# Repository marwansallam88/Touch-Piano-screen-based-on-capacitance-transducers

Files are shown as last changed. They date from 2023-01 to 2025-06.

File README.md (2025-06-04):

# Touch Piano Screen Based On Capacitance Transducers

## Project Overview
<p align="center">
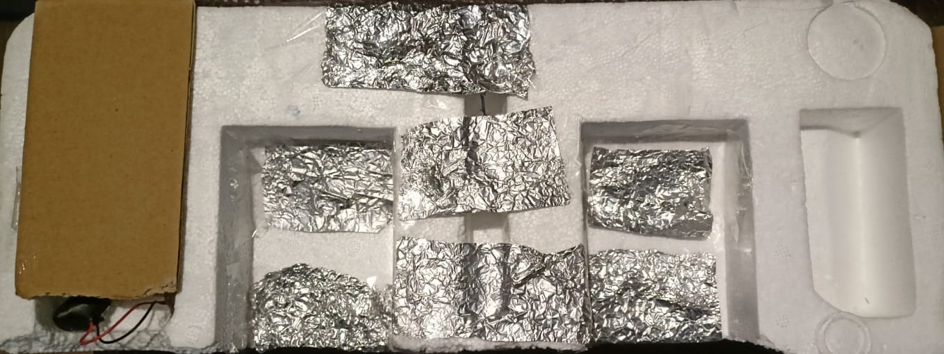
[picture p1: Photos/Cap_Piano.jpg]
Description
  
</p>

### Technical Concept
A microcontroller-based electronic piano that utilizes capacitive sensing technology to replace traditional mechanical keys. The system employs RC time constant measurements to detect touch inputs with variable sensitivity, enabling:
- Contactless note triggering
- Pressure-sensitive volume control (future implementation)
- Compact form factor with minimal moving parts

### System Architecture
-
  ```mermaid
  graph TD
      A[Capacitive Touch Pads] --> B[RC Circuit]
      B --> C[Arduino Nano]
      C --> D[PWM Tone Generation]
      D --> E[Passive Buzzer]
      C --> F[LED Feedback]

## Key Specifications

| Parameter           | Specification         | Measurement Method     |
|---------------------|------------------------|-------------------------|
| Input Range         | 1–174 ms               | RC time constant        |
| Output Resolution   | 7,908 units            | 10-bit ADC              |
| Sensitivity         | 394.4 units/ms         | Linear regression       |
| Frequency Response  | 5.7–997.6 rad/s        | Bode analysis           |
| Power Consumption   | <100mA @ 5V            | Current probe           |

---

## Technical Implementation

### Sensing System
<p align="center">
  <img src="Photos/Cap_Piano_Circuit.png" alt="Description" width="400"/>
</p>

- 7× copper PCB pads (20mm² each)  
- 1MΩ current-limiting resistors  
- CapacitiveSensor library for Arduino

### Control Unit
<p align="center">
  <img src="Photos/Cap_Piano_PCB.png" alt="Description" width="400"/>
</p>

- ATmega328P microcontroller  
- Custom PCB layout  
- 16MHz clock frequency

### Audio Output
- Passive piezoelectric buzzer  
- PWM-generated tones (C4–B4 frequency range)  
- 8Ω impedance

### Power Management
- 18650 Li-ion cell (3.7V nominal)  
- TP4056 charging module  
- MT3608 boost converter (to 5V)

---

## Performance Characteristics

### Transfer Function
-
    ```math
          H(s) = \frac{1}{\tau s + 1}, \quad \tau \in [0.001, 0.174] \text{ s}

### Bandwidth Variation

- **Untouched:** 997.6 rad/s (159 Hz)  
- **Fully pressed:** 5.7 rad/s (0.9 Hz)

---

## Statistical Analysis

| Metric                | Value             |
|------------------------|------------------|
| Resolution             | 7,908 units       |
| Sensitivity            | 394.4 units/ms    |
| Std. Deviation         | 3.12×10⁶          |
| Signal-to-Noise Ratio  | 42 dB             |

---

## Development Progress

### Research Phase
- Capacitive sensing literature review  
- Component selection analysis

### Prototyping
- Breadboard validation  
- Initial code development

### Production
- PCB design (Eagle)  
- SMT assembly process

### Validation
- Unit testing (per key)  
- Frequency response verification  
- Power consumption measurements

---

## Future Work

### Potential Implementations
- Pressure-sensitive volume control
- Multi-touch detection
- Octave expansion (14+ keys)
- Battery optimization for >24h runtime

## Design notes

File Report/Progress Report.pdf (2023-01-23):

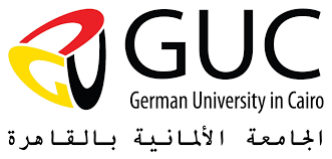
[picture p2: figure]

Faculty of Engineering and Material Science

Mechatronics Department

Assoc.Prof.Dr.Eng. Amir R. Ali

Winter 2022

# Sensor Technology ELCT 903

## Project Name: Touch Piano screen based on

## capacitance transducers

## Project Number: 35

## Team Number: 1

## Milestone Number: 5

First Member Name: | Amro Hassan (46-3027)
Second Member Name: | Ahmad Mady (46-0798)
Third Member Name: | Mohamad Magdy (46-3493)
Fourth Member Name: | Mostafa Kashaf (46-5456)
Fifth Member Name: | Marwan Sallam (46-3401)

## Brief review about touch capacitive piano:

The piano is played on a keyboard, which consists of a row of keys, and the player strikes the

keys with their fingers and thumbs to make the hammers strike the strings. As a result of the

hammers' rebound, the strings can keep vibrating at their resonance frequencies. The sounding

board receives these vibrations via the bridge, allowing for a more efficient coupling of the

acoustic energy to the air. Otherwise, the sound won't be louder than what the strings themselves

directly generate. The damper stops the string's vibration when the key is released. Then

afterwards came the digital or the electronic piano which used metal strings that magnetically

transmitted vibrations to an amplifier and loudspeaker. The analogue signal is amplified,

electronically altered with effects, and sent to speakers in an electrical piano. The upcoming

types of pianos are supposedly capacitive key pianos that can work just by touching it and most

recent projects tackle this problem. Recently, capacitive sensing has become a more attractive

and popular sensing mechanism for mechanical stimuli, especially in the sense of touch, with

good power consumption, sensitivity, and adaptive configurations of sensing. The enhancement

of the flexibility of the electrode material is an important issue since it is the primary component

of the wearable sensor. Conductive nanomaterial and polymers have been used as electrode

materials in capacitive sensors. Moreover, modified sensing interfaces and structures are also

explored to further enhance the sensitivity of the sensor. With all these advancements in the

capacitor the capacitive pianos have the possibility to work just by hovering over the keys and

can also distinguish between a long or short press thus outputting different audios or sounds on a

single key.

## Project idea and specifications:

The whole idea of the touch piano simply is using seven capacitive sensors as keys or inputs

where the microcontroller can recognize and differentiate them thus outputting seven different

audios using a passive buzzer according to the key that is pressed. Another possible feature that

can be implemented in this project is to adjust the volume of the different audio according to the

duration of the key press which are either a long press meaning higher volume and a short press

meaning lower volume and this can be done in future work once the first prototype is perfect. In

simple terms to make a capacitor all that’s needed are two parallel conductive plates which will

be the user’s finger and the part of the pcb where it has been etched separated by a dielectric

material which is air. Detecting the change of capacitance is not as easy as sensing the toggle of

the GPIO pin’s value or off. When the conductive plate is touched, the change in capacitance can

be detected using the “CapacitiveSensor” library in Arduino.

## Components list:

1x Arduino Nano | https://ram-e-shop.com/product/arduino-board-arduino-nano/
8x Resistors (1Mega Ohm) | https://ram-e-shop.com/product/fixed-resistances-125/

1x 18650 Battery cell https://ram-e-shop.com/product/lithium-rechargeable-battery-18650-3-7v-

purple-without-pins/

1x 18650 Battery cell holder https://ram-e-shop.com/product/battery-holder-18650x1/

1x 18650 battery Charging Module https://store.fut-electronics.com/collections/battery-

charger-accessory/products/lithium-battery-charger-and-protection-module

1x DC to DC Voltage Booster | https://ram-e-shop.com/product/dc-dc-200/
1x Passive Buzzer | https://store.fut-electronics.com/collections/buzzer/products/passive-

buzzer

1x PCB

# Progress Report:

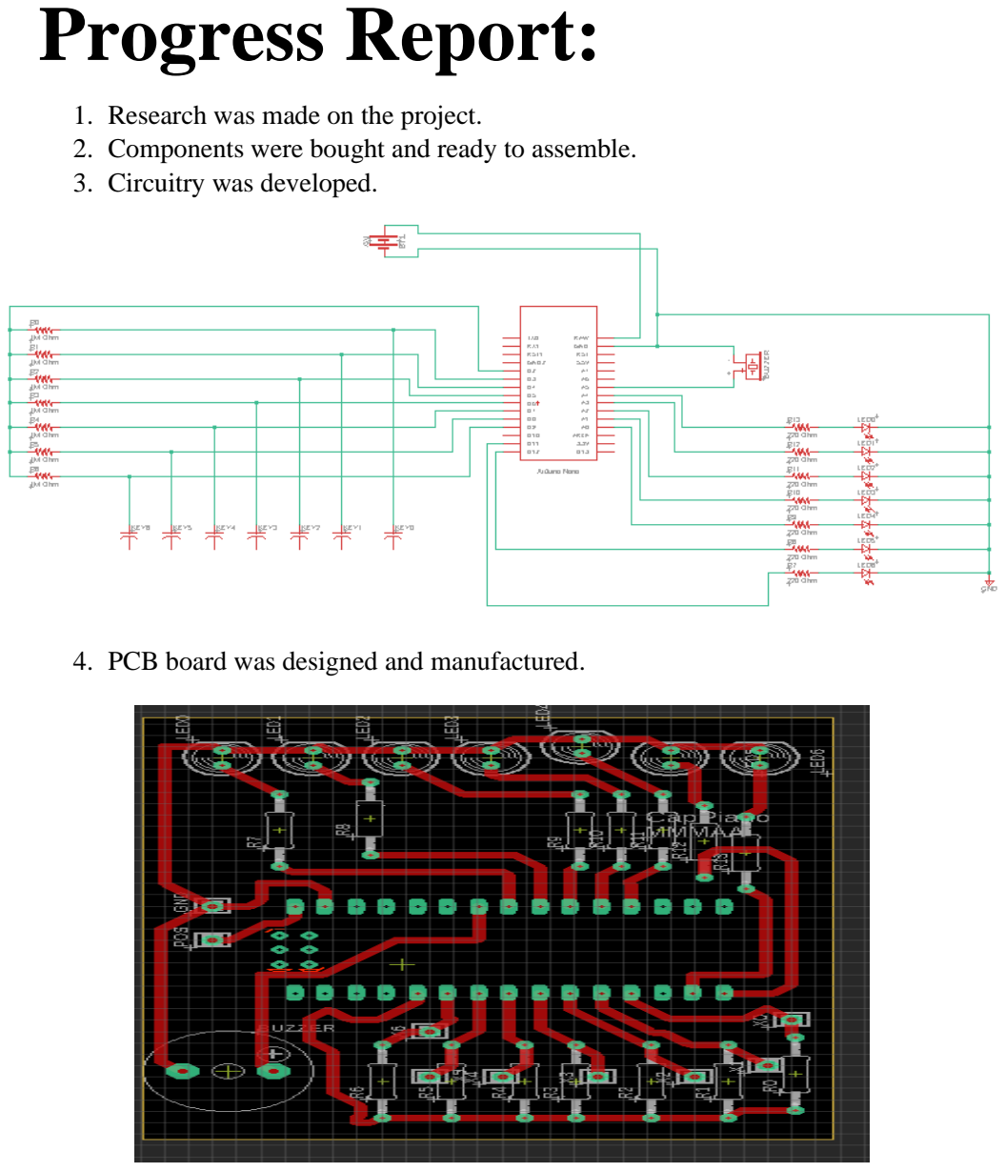
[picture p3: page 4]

1. Research was made on the project.
2. Components were bought and ready to assemble.
3. Circuitry was developed.
4. PCB board was designed and manufactured.

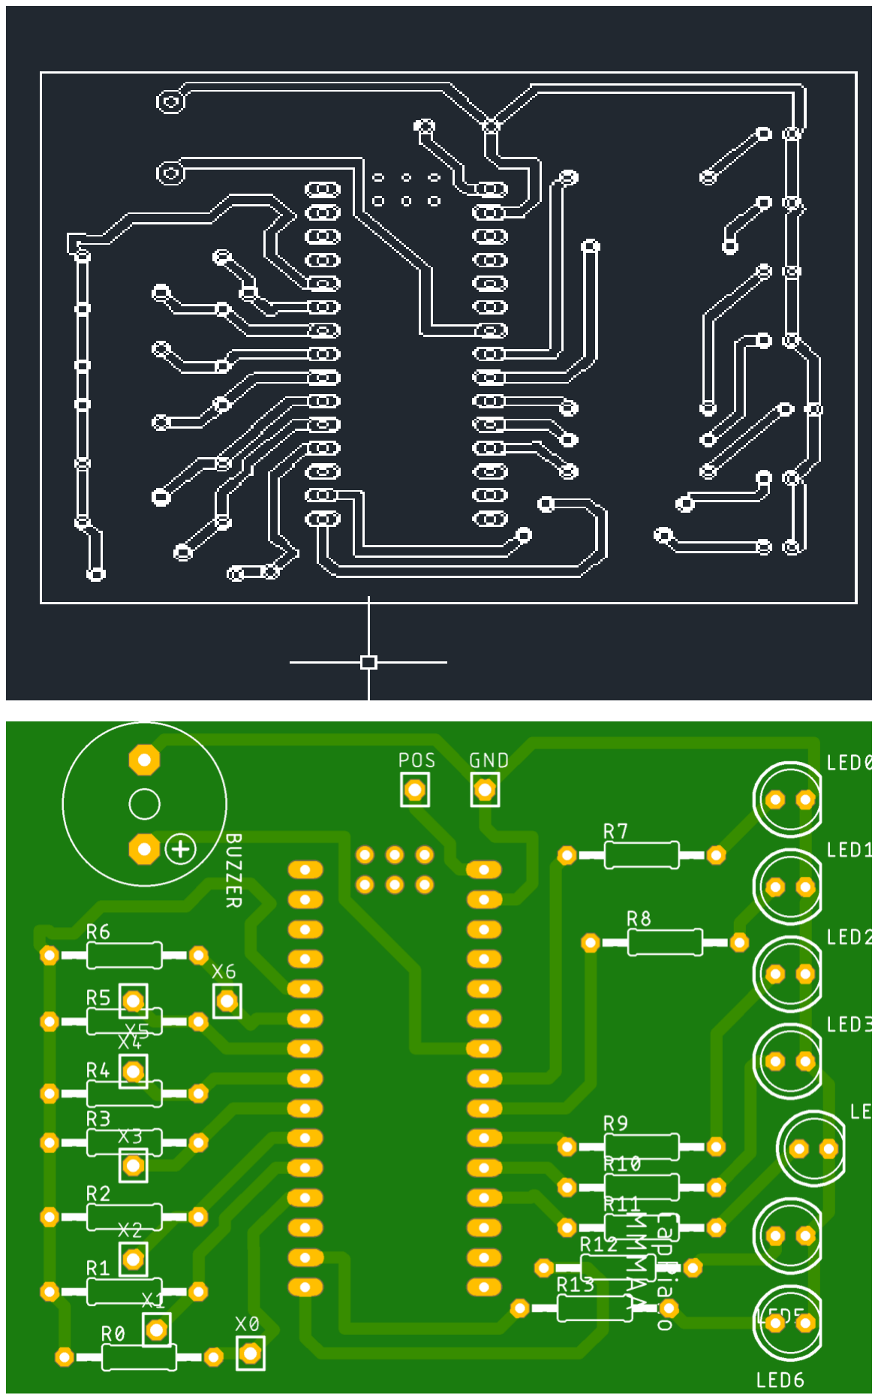
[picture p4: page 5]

5. Code was written and uploaded on Arduino. Basically, it works as follows: A sender pin sends signal to a receiver pin. Then Arduino measures the time it takes for the receiver a pin to receive the signal. As its well known in an RC circuit there some delay between input voltage and output voltage which is called the time constant and thus the Arduino measures this time and use it

to calculate the capacitance but in arbitrary units. The higher capacitance, the higher the time.

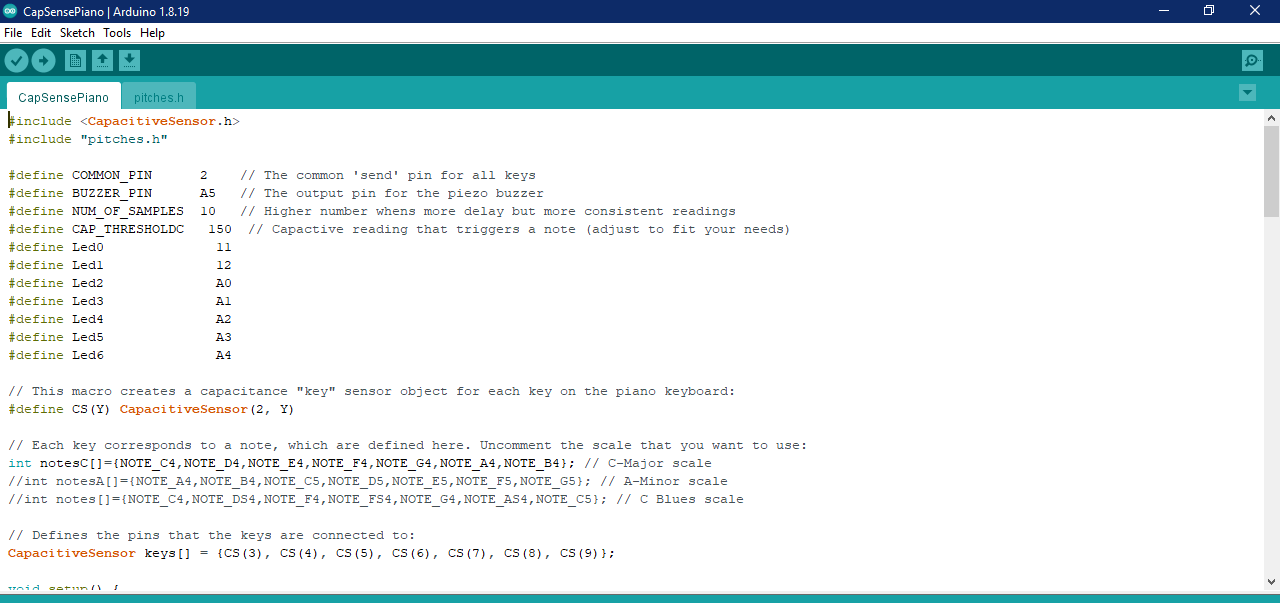
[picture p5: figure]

### 6. Code and circuitry were tested on a breadboard with the components to

make sure everything was working correctly.

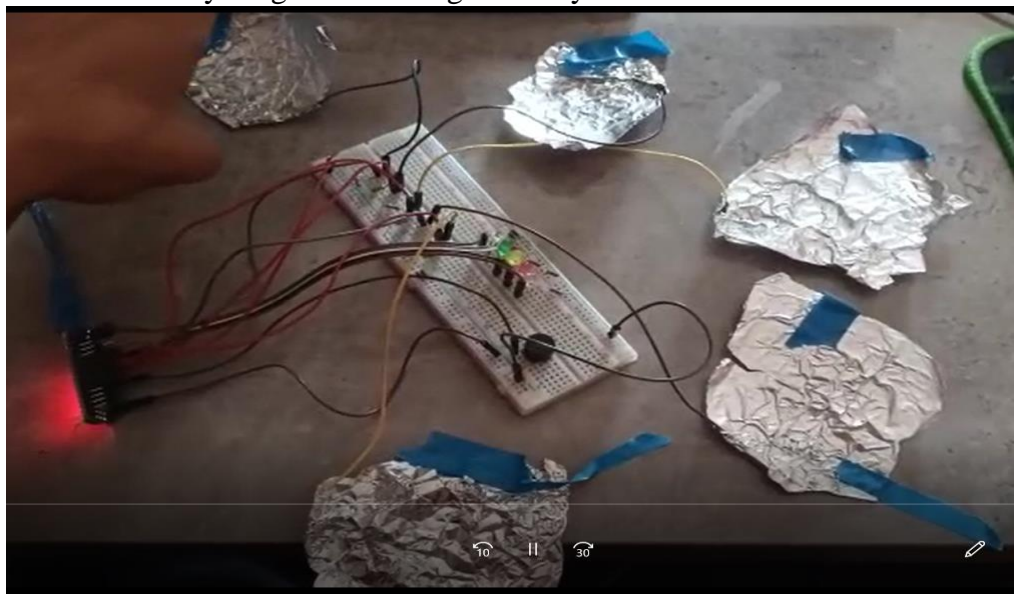
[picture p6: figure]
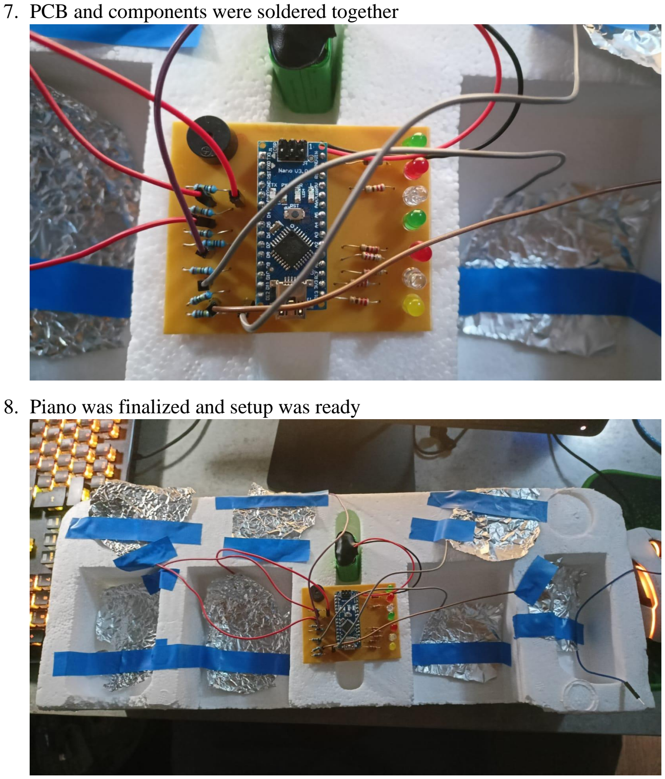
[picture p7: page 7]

### 7. PCB and components were soldered together

### 8. Piano was finalized and setup was ready

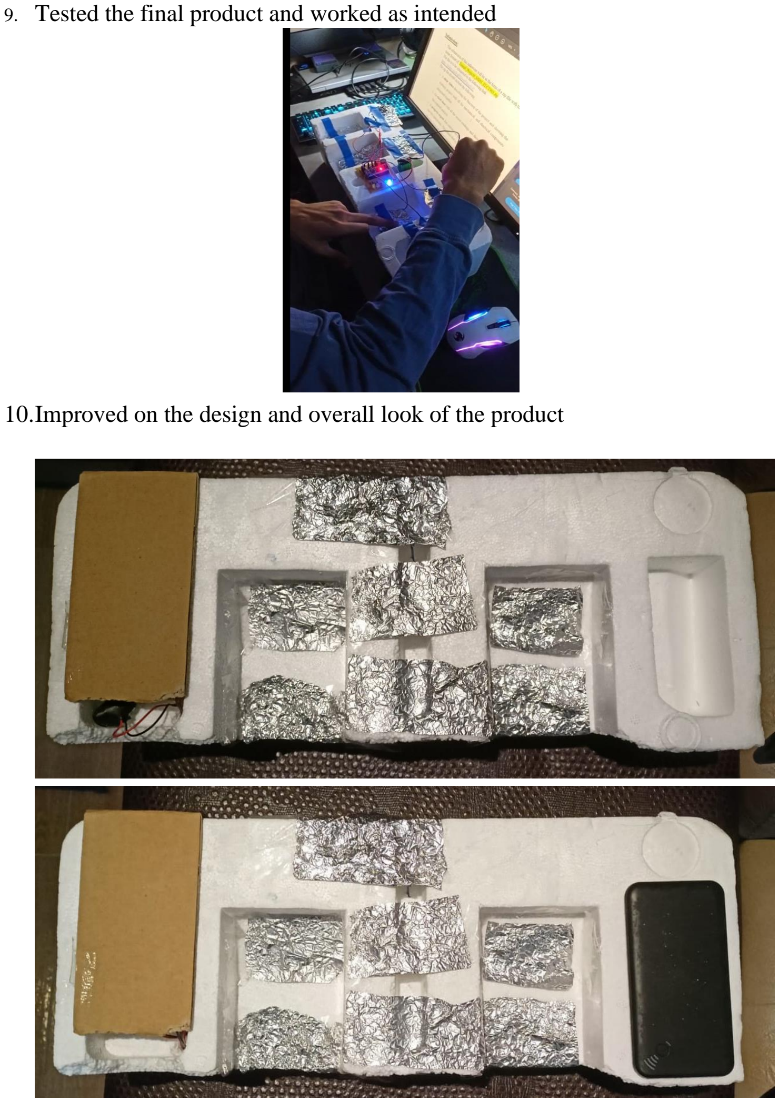
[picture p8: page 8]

### 9. Tested the final product and worked as intended

### 10.Improved on the design and overall look of the product

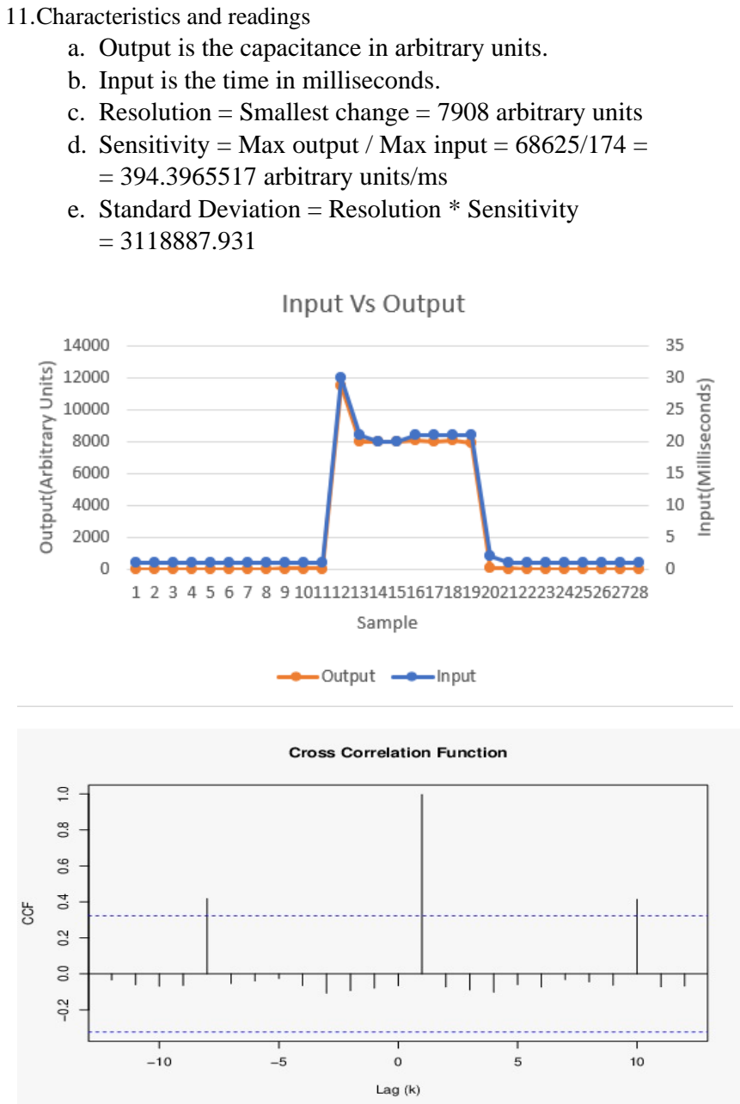
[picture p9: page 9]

### 11.Characteristics and readings

a. Output is the capacitance in arbitrary units.
b. Input is the time in milliseconds.

### c. Resolution = Smallest change = 7908 arbitrary units d. Sensitivity = Max output / Max input = 68625/174 = = 394.3965517 arbitrary units/ms e. Standard Deviation = Resolution * Sensitivity

= 3118887.931

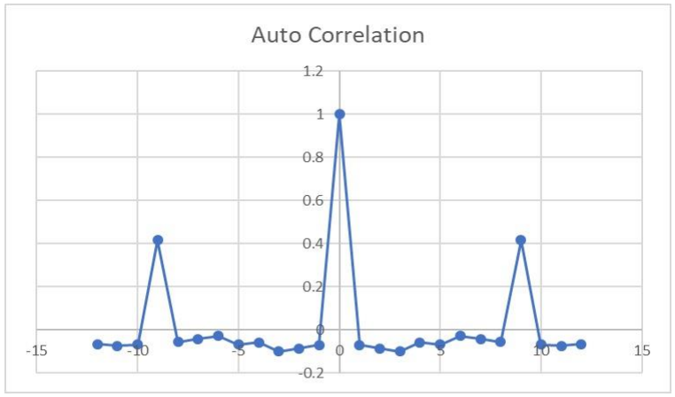
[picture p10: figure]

## Auto Correlation data

Lag | Value | Lag | Value
-12 | -0.0662062927941972 | 0 | 1
-11 | -0.0734925586884804 | 1 | -0.0705975011622147
-10 | -0.0691648171929965 | 2 | -0.0872463857498584
-9 | 0.416227475311117 | 3 | -0.100410006753664
-8 | -0.057048614727936 | 4 | -0.0579493781770414
-7 | -0.0429768616635528 | 5 | -0.0683886029991145
-6 | -0.0293223584648403 | 6 | -0.0293223584648403
-5 | -0.0683886029991145 | 7 | -0.0429768616635528
-4 | -0.0579493781770414 | 8 | -0.057048614727936
-3 | -0.100410006753664 | 9 | 0.416227475311117
-2 | -0.0872463857498584 | 10 | -0.0691648171929965
-1 | -0.0705975011622147 | 11 | -0.0734925586884804
| | 12 | -0.0662062927941972

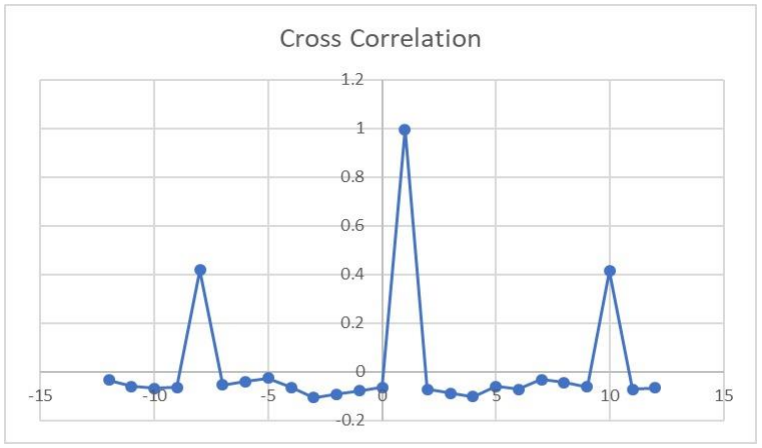
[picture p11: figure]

## Cross Correlation Data

Lag | Value | Lag | Value
-12 | -0.033552933583369 | 0 | -0.0653521394067079
-11 | -0.0606521017242916 | 1 | 0.996256864778712
-10 | -0.0679692200080865 | 2 | -0.0721238368185577
-9 | -0.0640923998830103 | 3 | -0.0888736820119851
-8 | 0.418626273898603 | 4 | -0.101987397425721
-7 | -0.0534586243471571 | 5 | -0.0596517514187829
-6 | -0.0396104332496399 | 6 | -0.0731209767303093
-5 | -0.0256047110006229 | 7 | -0.0318775446980341
-4 | -0.0648444493153413 | 8 | -0.0440842421777302
-3 | -0.106841982293459 | 9 | -0.0626140527663694
-2 | -0.0930269441936679 | 10 | 0.414056031301388
-1 | -0.0792197732757929 | 11 | -0.0715237719670072\
| | 12 | -0.0674413093998998

### f. Transfer function: The system is assumed to be a first order system with a varying

time constant as capacitance changes with respect to distance. TF = 1
Ts + 1

### Two cases were studied when pressed and when unpressed (High time and low time constant respectively)

### Test case 1: Not pressed; Low time constant around 1 millisecond

### TF = 1 0.001s + 1

### Bandwidth of the sensor when not touched at time constant 0.001: 997.6283 rad/s

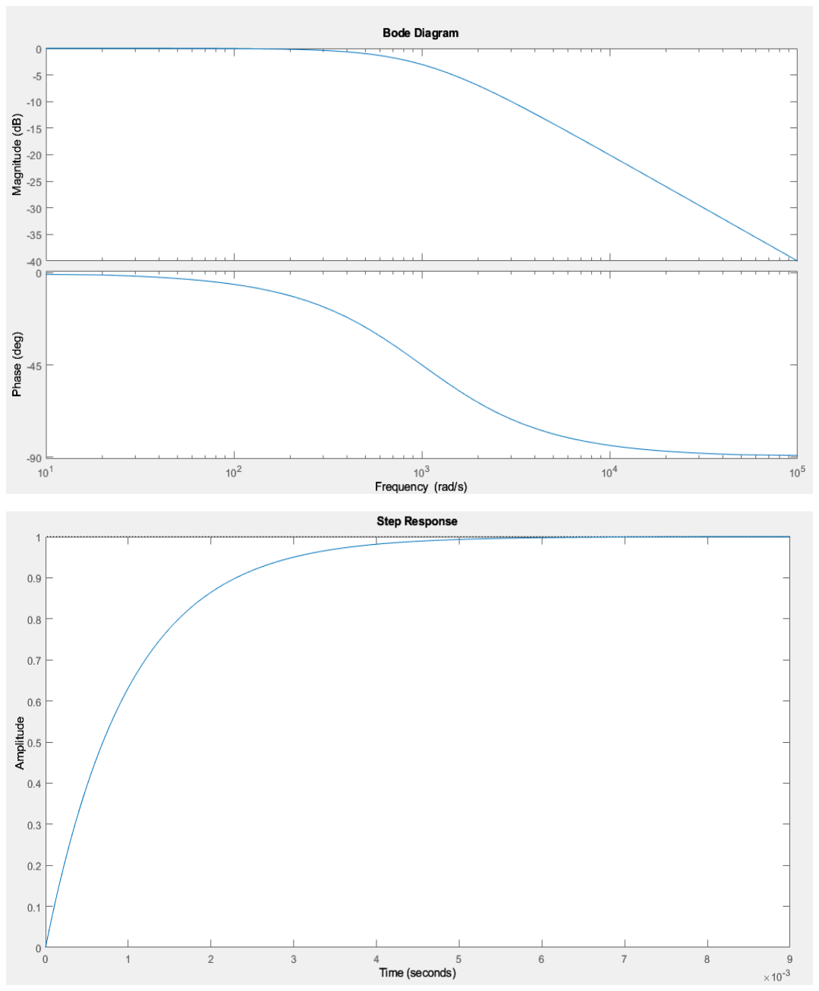
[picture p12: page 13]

### Test case 2: Pressed; How time constant around 174 milliseconds

### TF = 1 0.174s + 1

### Bandwidth of the sensor when not touched at time constant 0.174: 5.7335 rad/s

### Thus, the bandwidth can vary from 997.6283 rad/s to 5.7335

rad/s.

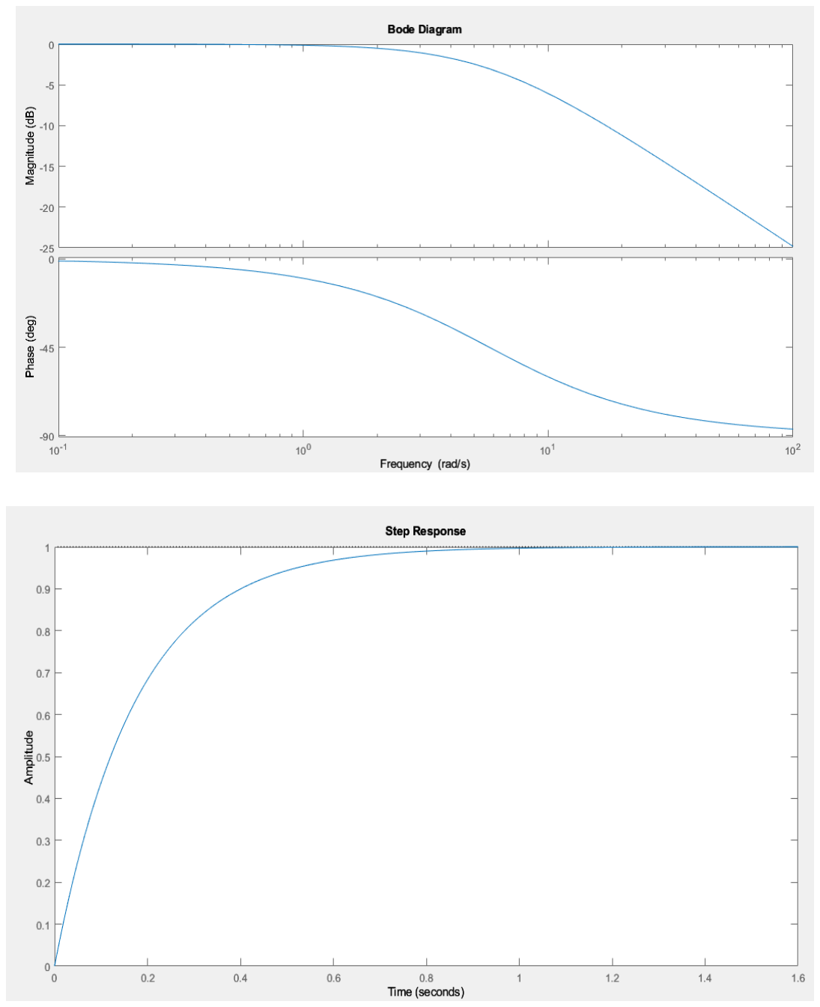
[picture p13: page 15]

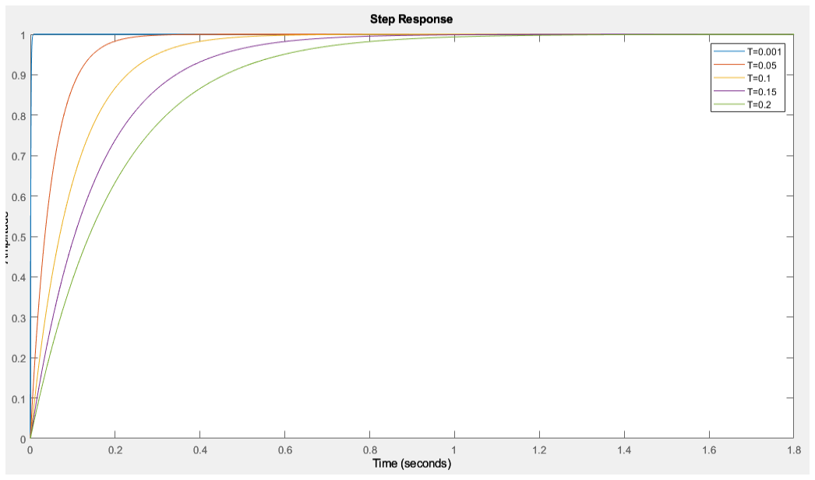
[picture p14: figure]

### As can be seen from the previous graph that as it takes longer to reach a steady

state that means the time constant is longer and thus the capacitance is higher.

### As the time constant increase, the response takes longer thus that means

capacitance has increased.

### Similarly, as seen here there is a direct relation between input which is time and

output which is capacitance in arbitrary units.

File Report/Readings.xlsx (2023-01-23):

First Readings | Second Readings | Third Readings |  | Fourth Readings |  | Info
0 | 23 | Input | Output | Input | Output
2 | 32 | 1 | 5 | 0 | 13
2 | 29 | 1 | 3 | 1 | 36 | Input is the time in milliseconds.
2 | 33 | 1 | 5 | 113 | 44652 | Output is the capacitance in arbitrary units.
3 | 32 | 1 | 3 | 1 | 31 | Resolution = Smallest change = | 7908 | arbitrary units
1 | 26 | 1 | 5 | 0 | 16 | Sensitivity = Max output / Max input = | 394.3965517 | arbitrary units/ms
3 | 31 | 1 | 10 | 0 | 13 | Standard Deviattion = Resoltuion * Sensitvity = | 3118887.931
1 | 33 | 1 | 11 | 0 | 13 | Untouched button example | Low value ranging around 0~100
3 | 33 | 1 | 10 | 0 | 16 | Touched button example | High values above 5000
1 | 30 | 1 | 12 | 0 | 13
3 | 3457 | 1 | 14 | 0 | 13
3 | 7820 | 1 | 12 | 0 | 13
3 | 11651 | 30 | 11450 | 0 | 13
0 | 11664 | 21 | 7968 | 174 | 68625
3 | 7926 | 20 | 7952 | 0 | 13
1 | 11627 | 20 | 7999 | 0 | 16
3 | 7923 | 21 | 8079
0 | 7926 | 21 | 7999
3 | 7915 | 21 | 8088
1 | 7952 | 21 | 7908
3 | 7964 | 2 | 23
0 | 7972 | 1 | 12
3 | 7922 | 1 | 11
2 | 7933 | 1 | 1
3 | 7901 | 1 | 2
3 | 7924 | 1 | 2
3 | 7860 | 1 | 1
1 | 7913 | 1 | 3
3 | 3834 | 1 | 3
0 | 31
3 | 19
3 | 13
3 | 31
1 | 30
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

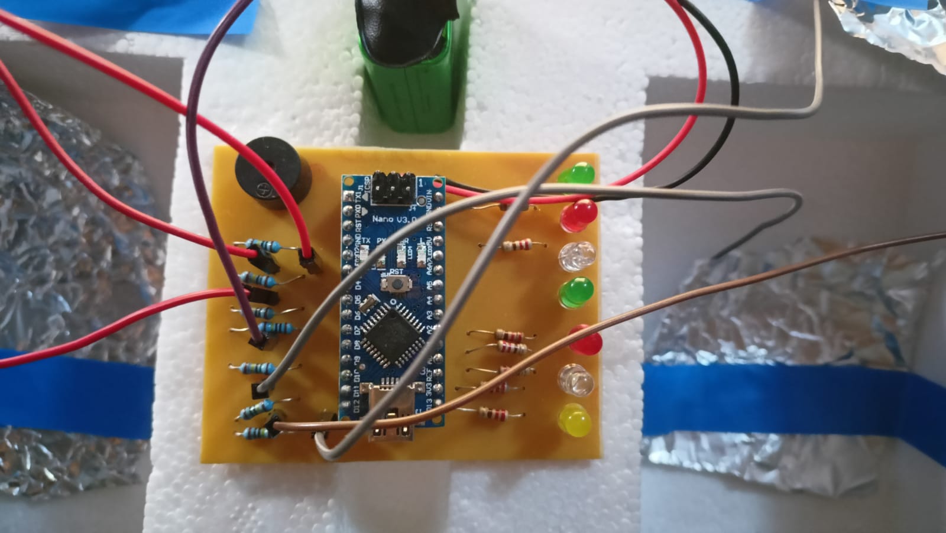
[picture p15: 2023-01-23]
Report/PCB.jpg

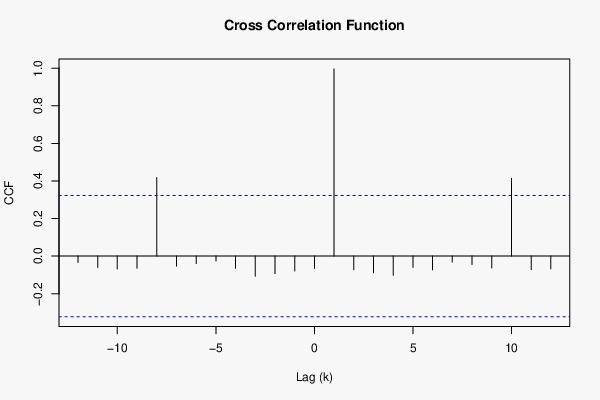
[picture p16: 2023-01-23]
Report/Cross Function.jpg

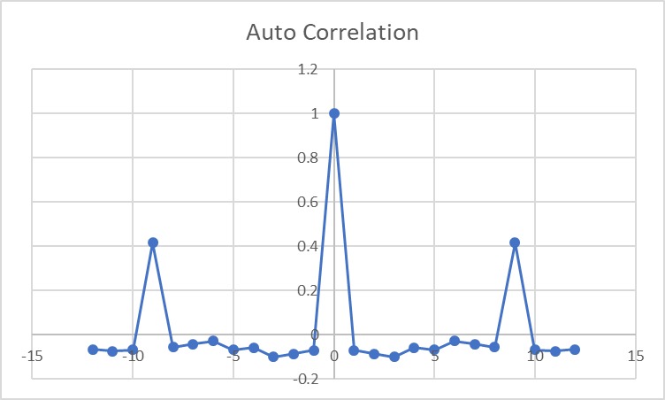
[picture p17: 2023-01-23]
Report/Auto Correlation.jpg

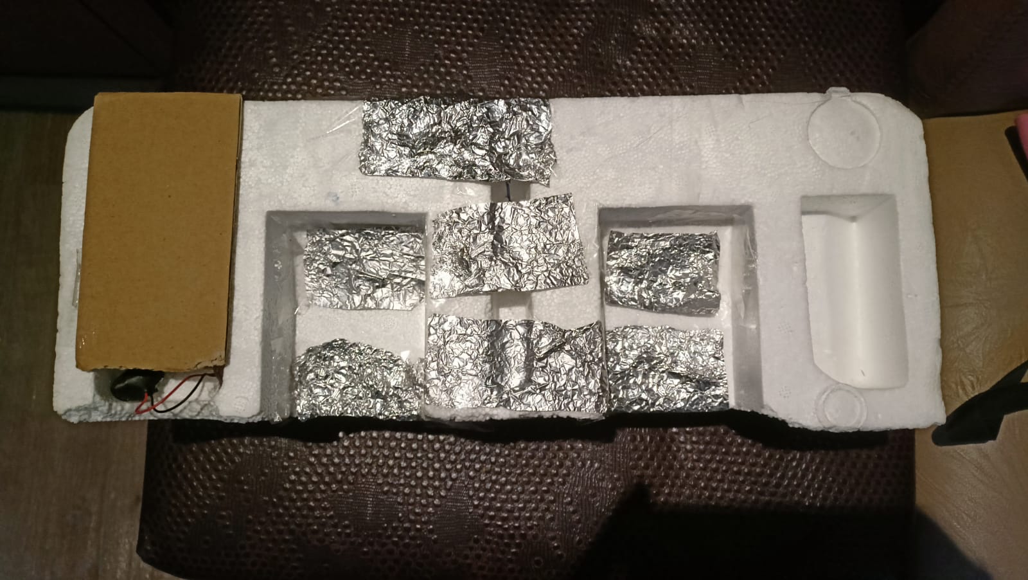
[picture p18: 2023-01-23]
Report/Finalized product.jpg

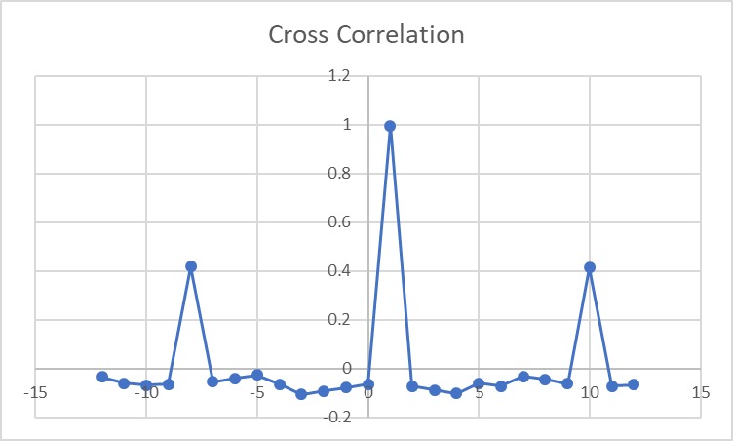
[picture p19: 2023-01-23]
Report/Cross Correlation.jpg

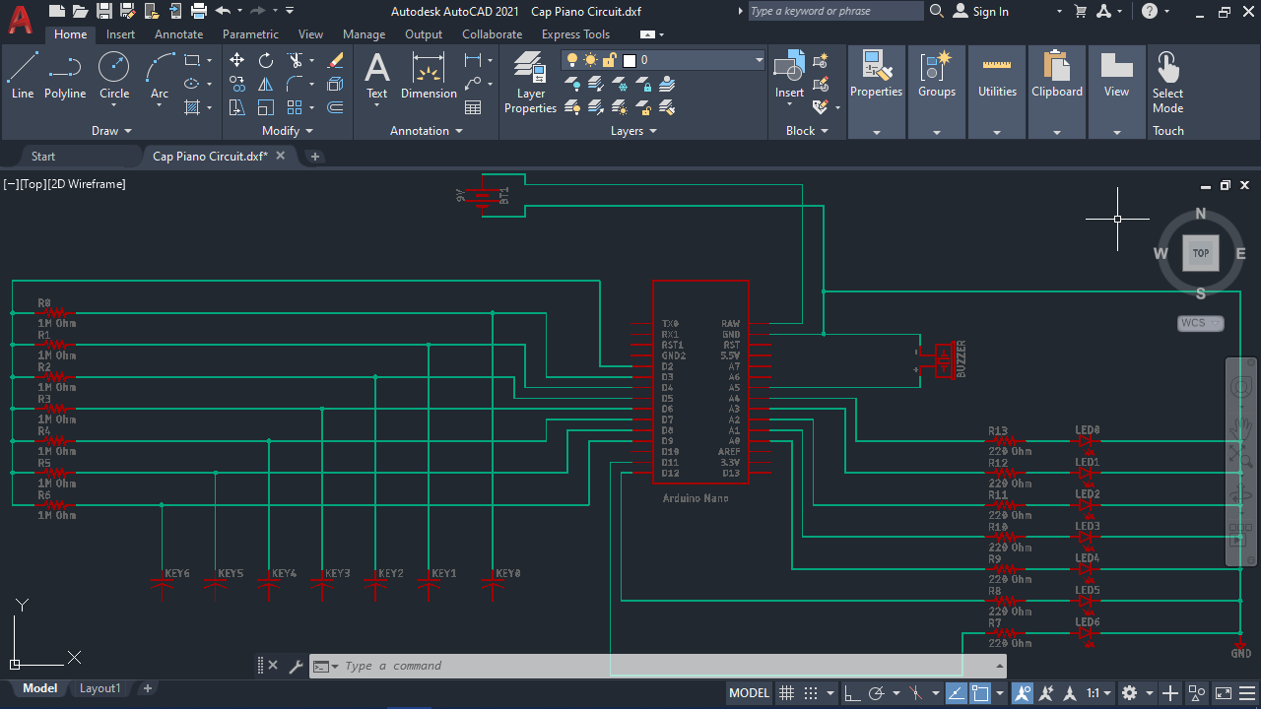
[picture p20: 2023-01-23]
Photos/Cap_Piano_Circuit.png

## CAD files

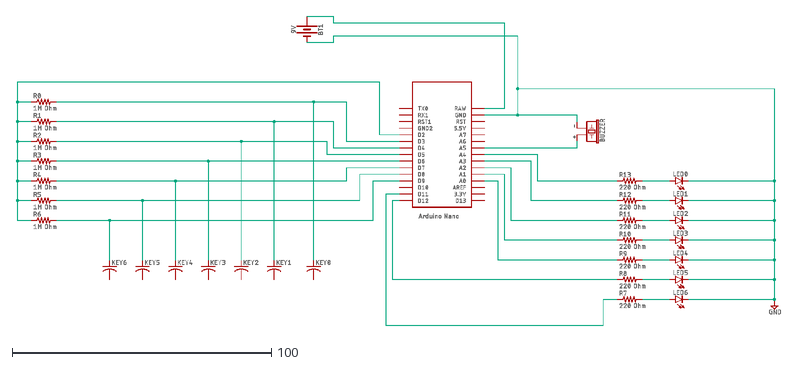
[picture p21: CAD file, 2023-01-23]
Eagle/Circuit/Cap Piano Circuit.dxf
295.1 x 119.5

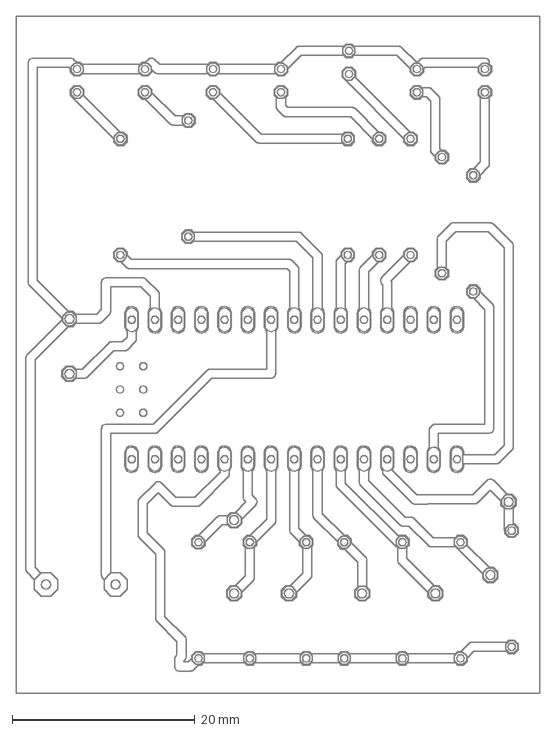
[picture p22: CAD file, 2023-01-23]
Eagle/PCB/Cap Piano - PCB.dxf
57.2 x 74.0 mm

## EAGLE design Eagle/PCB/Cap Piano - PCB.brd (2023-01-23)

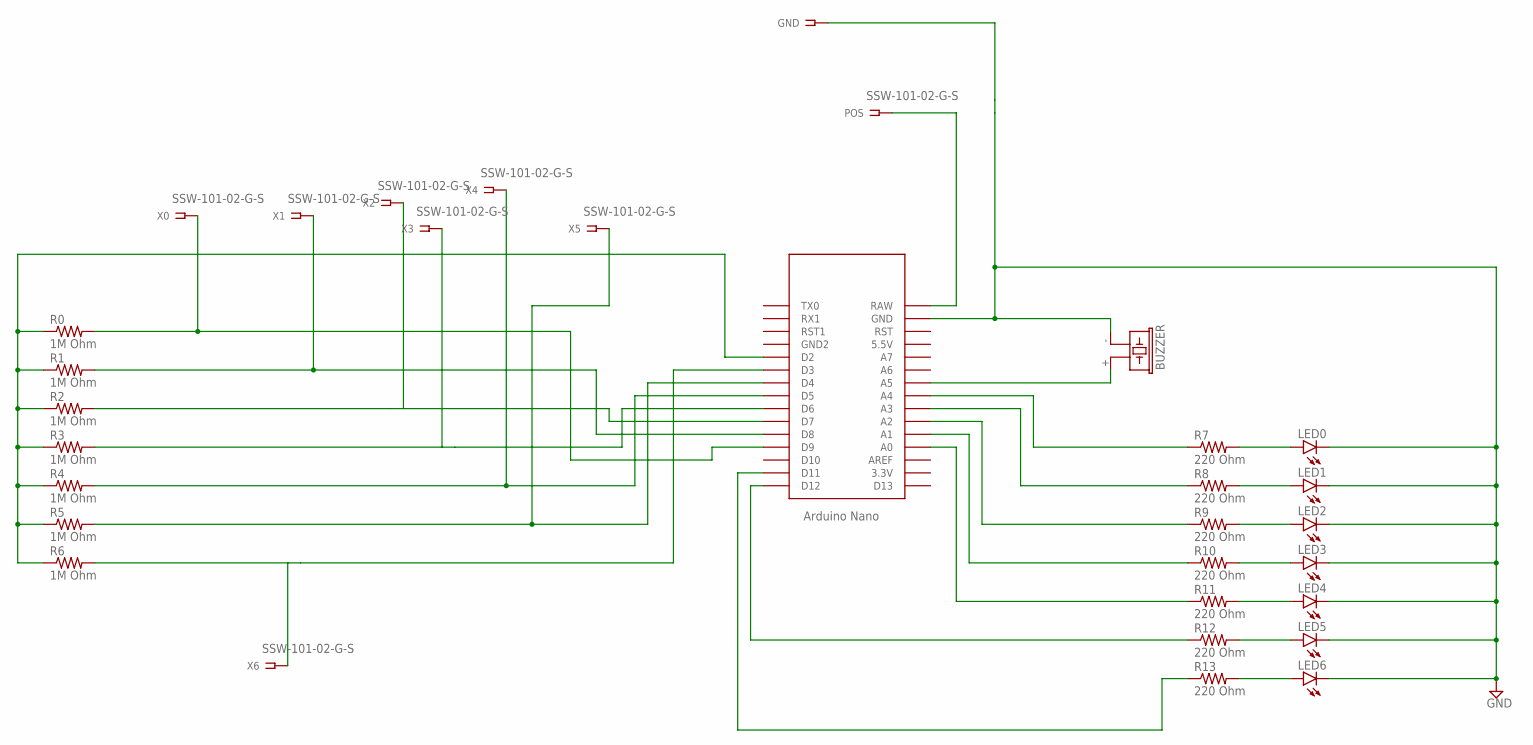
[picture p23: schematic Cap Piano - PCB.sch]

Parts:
BUZZER: F/CM12P
GND: SSW-101-02-G-S
LED0, LED1, LED2, LED3, LED4, LED5, LED6: LED5MM
POS: SSW-101-02-G-S
R0, R1, R2, R3, R4, R5, R6: 1M Ohm; 0207/12
R7, R8, R9, R10, R11, R12, R13: 220 Ohm; 0207/12
U$1: NANO
X0, X1, X2, X3, X4, X5, X6: SSW-101-02-G-S

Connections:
GND: BUZZER.- (2), GND.1, LED0.K (C), LED1.K (C), LED2.K (C), LED3.K (C), LED4.K (C), LED5.K (C), LED6.K (C), U$1.GND
unnamed: POS.1, U$1.RAW
unnamed: R5.2, U$1.D4, X5.1
unnamed: BUZZER.+ (1), U$1.A5
unnamed: R4.2, U$1.D5, X4.1
unnamed: R0.1, R1.1, R2.1, R3.1, R4.1, R5.1, R6.1, U$1.D2
unnamed: R6.2, U$1.D3, X6.1
unnamed: R3.2, U$1.D6, X3.1
unnamed: R2.2, U$1.D7, X2.1
unnamed: R1.2, U$1.D8, X1.1
unnamed: R0.2, U$1.D9, X0.1
unnamed: R13.1, U$1.D11
unnamed: R12.1, U$1.D12
unnamed: R11.1, U$1.A0
unnamed: R10.1, U$1.A1
unnamed: R9.1, U$1.A2
unnamed: R8.1, U$1.A3
unnamed: R7.1, U$1.A4
unnamed: LED0.A, R7.2
unnamed: LED1.A, R8.2
unnamed: LED2.A, R9.2
unnamed: LED3.A, R10.2
unnamed: LED4.A, R11.2
unnamed: LED5.A, R12.2
unnamed: LED6.A, R13.2

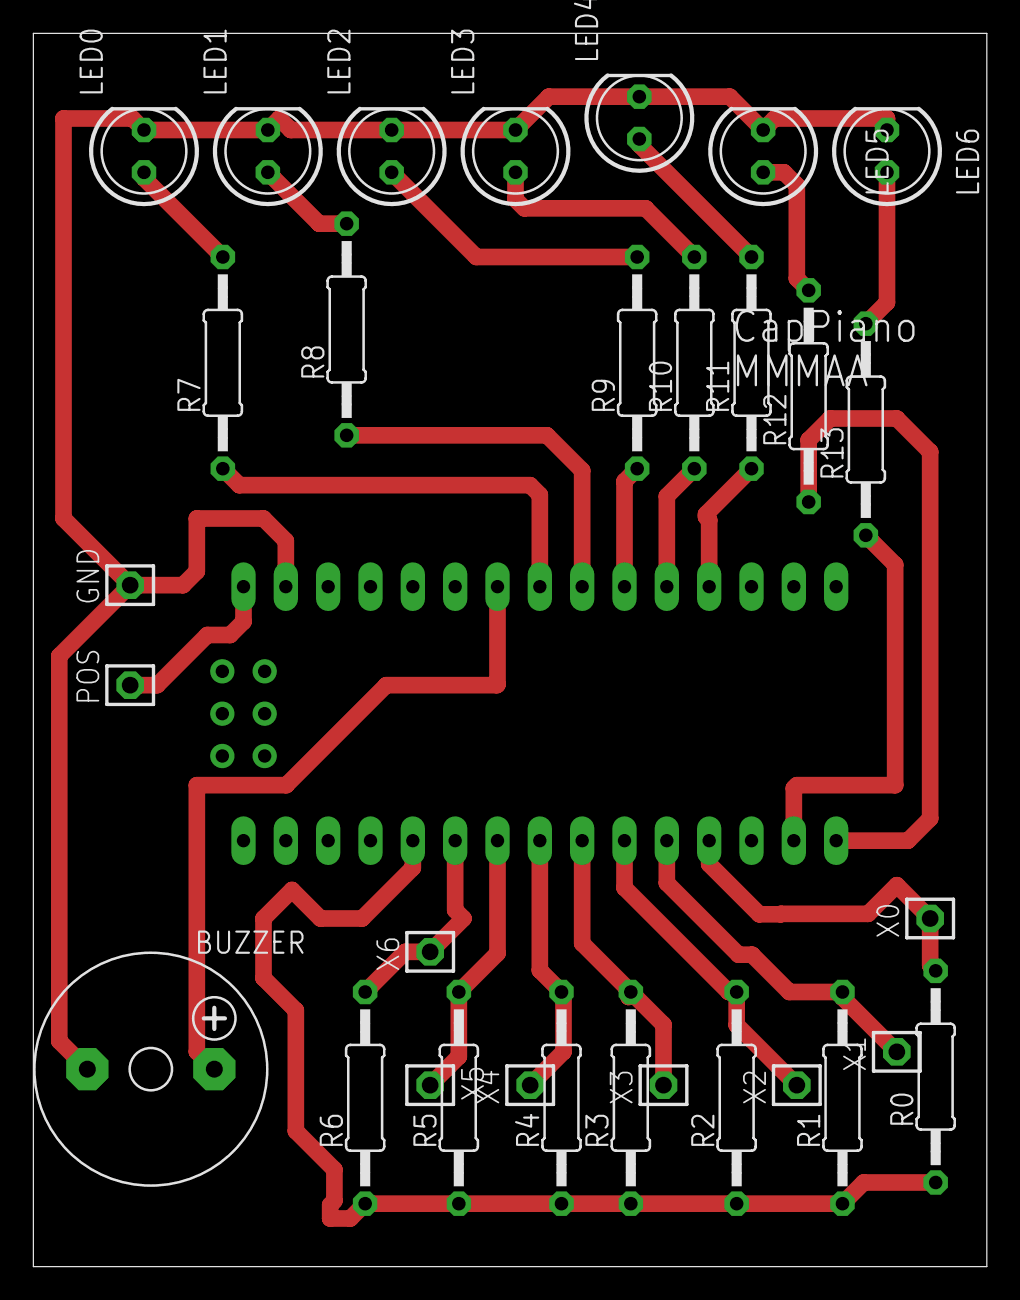
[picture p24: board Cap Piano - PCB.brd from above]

Board: 2 copper layers, 57.2 x 74.0 mm, 32 parts (0 on the bottom side), 25 nets.

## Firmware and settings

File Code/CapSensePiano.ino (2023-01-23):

#include <CapacitiveSensor.h>
#include "pitches.h"

#define COMMON_PIN      2    // The common 'send' pin for all keys
#define BUZZER_PIN      A5   // The output pin for the piezo buzzer
#define NUM_OF_SAMPLES  10   // Higher number means more delay but more consistent readings
#define CAP_THRESHOLDC   100  // Capactive reading that triggers a note (adjust to fit your needs)
#define Led0              11
#define Led1              12
#define Led2              A0
#define Led3              A1
#define Led4              A2
#define Led5              A3
#define Led6              A4

// This macro creates a capacitance "key" sensor object for each key on the piano keyboard:
#define CS(Y) CapacitiveSensor(2, Y)

// Each key corresponds to a note, which are defined here. Uncomment the scale that you want to use:
int notesC[]={NOTE_C4,NOTE_D4,NOTE_E4,NOTE_F4,NOTE_G4,NOTE_A4,NOTE_B4}; // C-Major scale
//int notesA[]={NOTE_A4,NOTE_B4,NOTE_C5,NOTE_D5,NOTE_E5,NOTE_F5,NOTE_G5}; // A-Minor scale
//int notes[]={NOTE_C4,NOTE_DS4,NOTE_F4,NOTE_FS4,NOTE_G4,NOTE_AS4,NOTE_C5}; // C Blues scale

// Defines the pins that the keys are connected to:
CapacitiveSensor keys[] = {CS(3), CS(4), CS(5), CS(6), CS(7), CS(8), CS(9)};

void setup() { 
  // Turn off autocalibrate on all channels:
  for(int i=0; i<7; ++i) {
    keys[i].set_CS_AutocaL_Millis(0xFFFFFFFF);
  }
  // Set the buzzer and leds as output:
  pinMode(BUZZER_PIN, OUTPUT);
  pinMode(Led0, OUTPUT); 
  pinMode(Led1, OUTPUT);
  pinMode(Led2, OUTPUT); 
  pinMode(Led3, OUTPUT);
  pinMode(Led4, OUTPUT); 
  pinMode(Led5, OUTPUT);
  pinMode(Led6, OUTPUT); 
  Serial.begin(9600);
}

void loop() {    
  if(keys[0].capacitiveSensor(NUM_OF_SAMPLES) > CAP_THRESHOLDC) {
    Serial.println(keys[0].capacitiveSensor(NUM_OF_SAMPLES));
    tone(BUZZER_PIN, notesC[0]);
    digitalWrite(Led0,HIGH);
    digitalWrite(Led1,LOW);
    digitalWrite(Led2,LOW);
    digitalWrite(Led3,LOW);
    digitalWrite(Led4,LOW);
    digitalWrite(Led5,LOW);
    digitalWrite(Led6,LOW);
  }
  if(keys[1].capacitiveSensor(NUM_OF_SAMPLES) > CAP_THRESHOLDC) {
    tone(BUZZER_PIN, notesC[1]);
    digitalWrite(Led0,LOW);
    digitalWrite(Led1,HIGH);
    digitalWrite(Led2,LOW);
    digitalWrite(Led3,LOW);
    digitalWrite(Led4,LOW);
    digitalWrite(Led5,LOW);
    digitalWrite(Led6,LOW);
  }
  if(keys[2].capacitiveSensor(NUM_OF_SAMPLES) > CAP_THRESHOLDC) {
    tone(BUZZER_PIN, notesC[2]);
    digitalWrite(Led0,LOW);
    digitalWrite(Led1,LOW);
    digitalWrite(Led2,HIGH);
    digitalWrite(Led3,LOW);
    digitalWrite(Led4,LOW);
    digitalWrite(Led5,LOW);
    digitalWrite(Led6,LOW);
  }
  if(keys[3].capacitiveSensor(NUM_OF_SAMPLES) > CAP_THRESHOLDC) {
    tone(BUZZER_PIN, notesC[3]);
    digitalWrite(Led0,LOW);
    digitalWrite(Led1,LOW);
    digitalWrite(Led2,LOW);
    digitalWrite(Led3,HIGH);
    digitalWrite(Led4,LOW);
    digitalWrite(Led5,LOW);
    digitalWrite(Led6,LOW);
  }
  if(keys[4].capacitiveSensor(NUM_OF_SAMPLES) > CAP_THRESHOLDC) {
    tone(BUZZER_PIN, notesC[4]);
    digitalWrite(Led0,LOW);
    digitalWrite(Led1,LOW);
    digitalWrite(Led2,LOW);
    digitalWrite(Led3,LOW);
    digitalWrite(Led4,HIGH);
    digitalWrite(Led5,LOW);
    digitalWrite(Led6,LOW);
  }
  if(keys[5].capacitiveSensor(NUM_OF_SAMPLES) > CAP_THRESHOLDC) {
    tone(BUZZER_PIN, notesC[5]);
    digitalWrite(Led0,LOW);
    digitalWrite(Led1,LOW);
    digitalWrite(Led2,LOW);
    digitalWrite(Led3,LOW);
    digitalWrite(Led4,LOW);
    digitalWrite(Led5,HIGH);
    digitalWrite(Led6,LOW);
  }
  if(keys[6].capacitiveSensor(NUM_OF_SAMPLES) > CAP_THRESHOLDC) {
    tone(BUZZER_PIN, notesC[6]);
    digitalWrite(Led0,LOW);
    digitalWrite(Led1,LOW);
    digitalWrite(Led2,LOW);
    digitalWrite(Led3,LOW);
    digitalWrite(Led4,LOW);
    digitalWrite(Led5,LOW);
    digitalWrite(Led6,HIGH);
  }
  if(keys[0].capacitiveSensor(NUM_OF_SAMPLES) < CAP_THRESHOLDC && 
  keys[1].capacitiveSensor(NUM_OF_SAMPLES) < CAP_THRESHOLDC && 
  keys[2].capacitiveSensor(NUM_OF_SAMPLES) < CAP_THRESHOLDC && 
  keys[3].capacitiveSensor(NUM_OF_SAMPLES) < CAP_THRESHOLDC && 
  keys[4].capacitiveSensor(NUM_OF_SAMPLES) < CAP_THRESHOLDC &&
  keys[5].capacitiveSensor(NUM_OF_SAMPLES) < CAP_THRESHOLDC && 
  keys[6].capacitiveSensor(NUM_OF_SAMPLES) < CAP_THRESHOLDC){
    Serial.println(keys[0].capacitiveSensor(NUM_OF_SAMPLES));
    noTone(BUZZER_PIN);
    digitalWrite(Led0,LOW);
    digitalWrite(Led1,LOW);
    digitalWrite(Led2,LOW);
    digitalWrite(Led3,LOW);
    digitalWrite(Led4,LOW);
    digitalWrite(Led5,LOW);
    digitalWrite(Led6,LOW);
  }
}

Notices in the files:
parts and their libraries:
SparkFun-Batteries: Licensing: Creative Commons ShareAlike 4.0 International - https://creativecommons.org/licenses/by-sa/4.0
